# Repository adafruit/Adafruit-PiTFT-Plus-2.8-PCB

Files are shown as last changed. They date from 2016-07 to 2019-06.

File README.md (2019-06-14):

## Adafruit PiTFT 2.8 Plus PCB

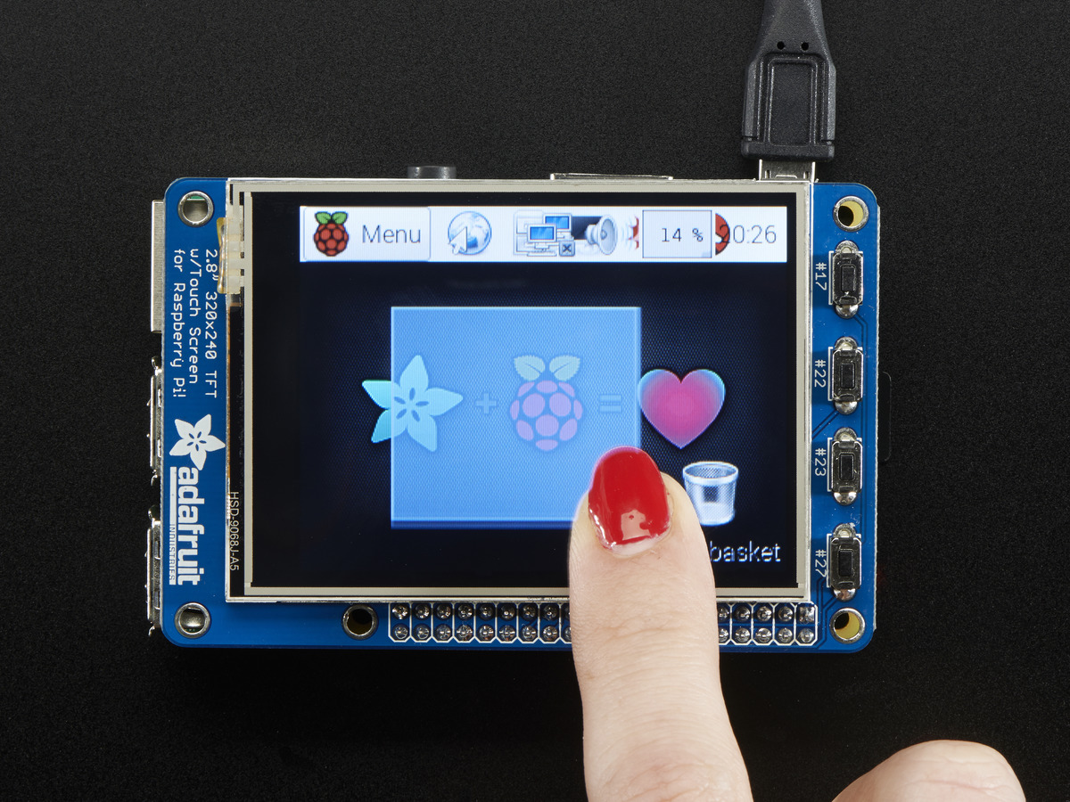
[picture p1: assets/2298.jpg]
&nbsp; 
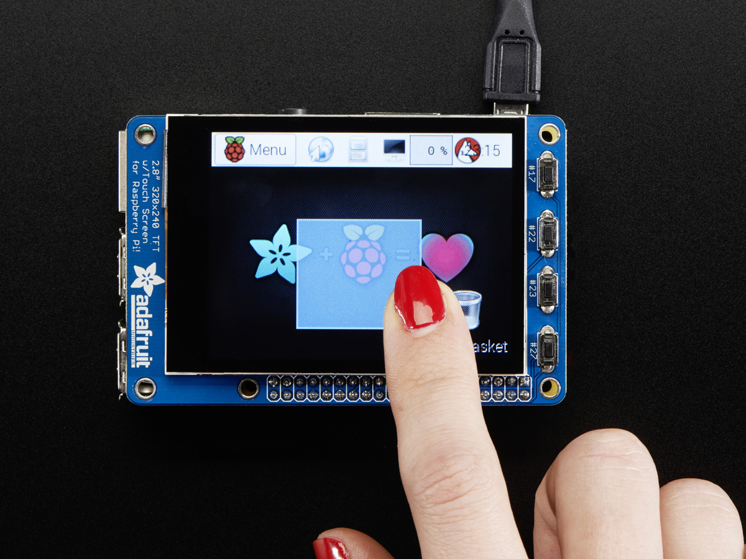
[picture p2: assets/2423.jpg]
<br/>
Click the image or links below to go to a specific product in the Adafruit shop.

PCB files for the Adafruit PiTFT Plus 2.8" Display. Format is EagleCAD schematic and board layout
* Resistive Screen https://www.adafruit.com/product/2298
* Capacitive Touch Screen https://www.adafruit.com/product/2423

### DESCRIPTION
Are these not the cutest little displays for the Raspberry Pi? They feature a 2.8" display with 320x240 16-bit color pixels and a  resistive touchscreen or capacitive touch overlay..

This updated design fits perfectly onto the Pi Zero, Pi 3, Pi 2 or Model A+, B+! (Any Pi with a 2x20 connector) Not for use with an old Pi 1 with 2x13 connector If you'd like to use a 2.8" display with the original Pi A or Pi B, check out the Model B version. This version also has all 40 pins GPIO pins brought out so you can connect a 40-pin GPIO cable underneath. Now that it's the same outline as a Pi 3/2/B+ it fits well on top of a Pi in our Raspberry Pi Enclosure base and can use our faceplate for a compact touchscreen Pi

The display and touchscreen uses the hardware I2C Pins (SDA & SCL), SPI pins (SCK, MOSI, MISO, CE0) as well as GPIO #25 and #24. All other GPIO are unused and you can still share the I2C pins with sensors, LED drivers, etc. Since we had a tiny bit of space, there's 4 slim tactile switches wired to four GPIOs, that you can use if you want to make a basic user interface. For example, you can use one as a power on/off button.

### License

Adafruit invests time and resources providing this open source design, please support Adafruit and open-source hardware by purchasing products from [Adafruit.com](https://www.adafruit.com)!

Creative Commons Attribution, Share-Alike license, check license.txt for more information All text above must be included in any redistribution - 
See license.txt for more information.

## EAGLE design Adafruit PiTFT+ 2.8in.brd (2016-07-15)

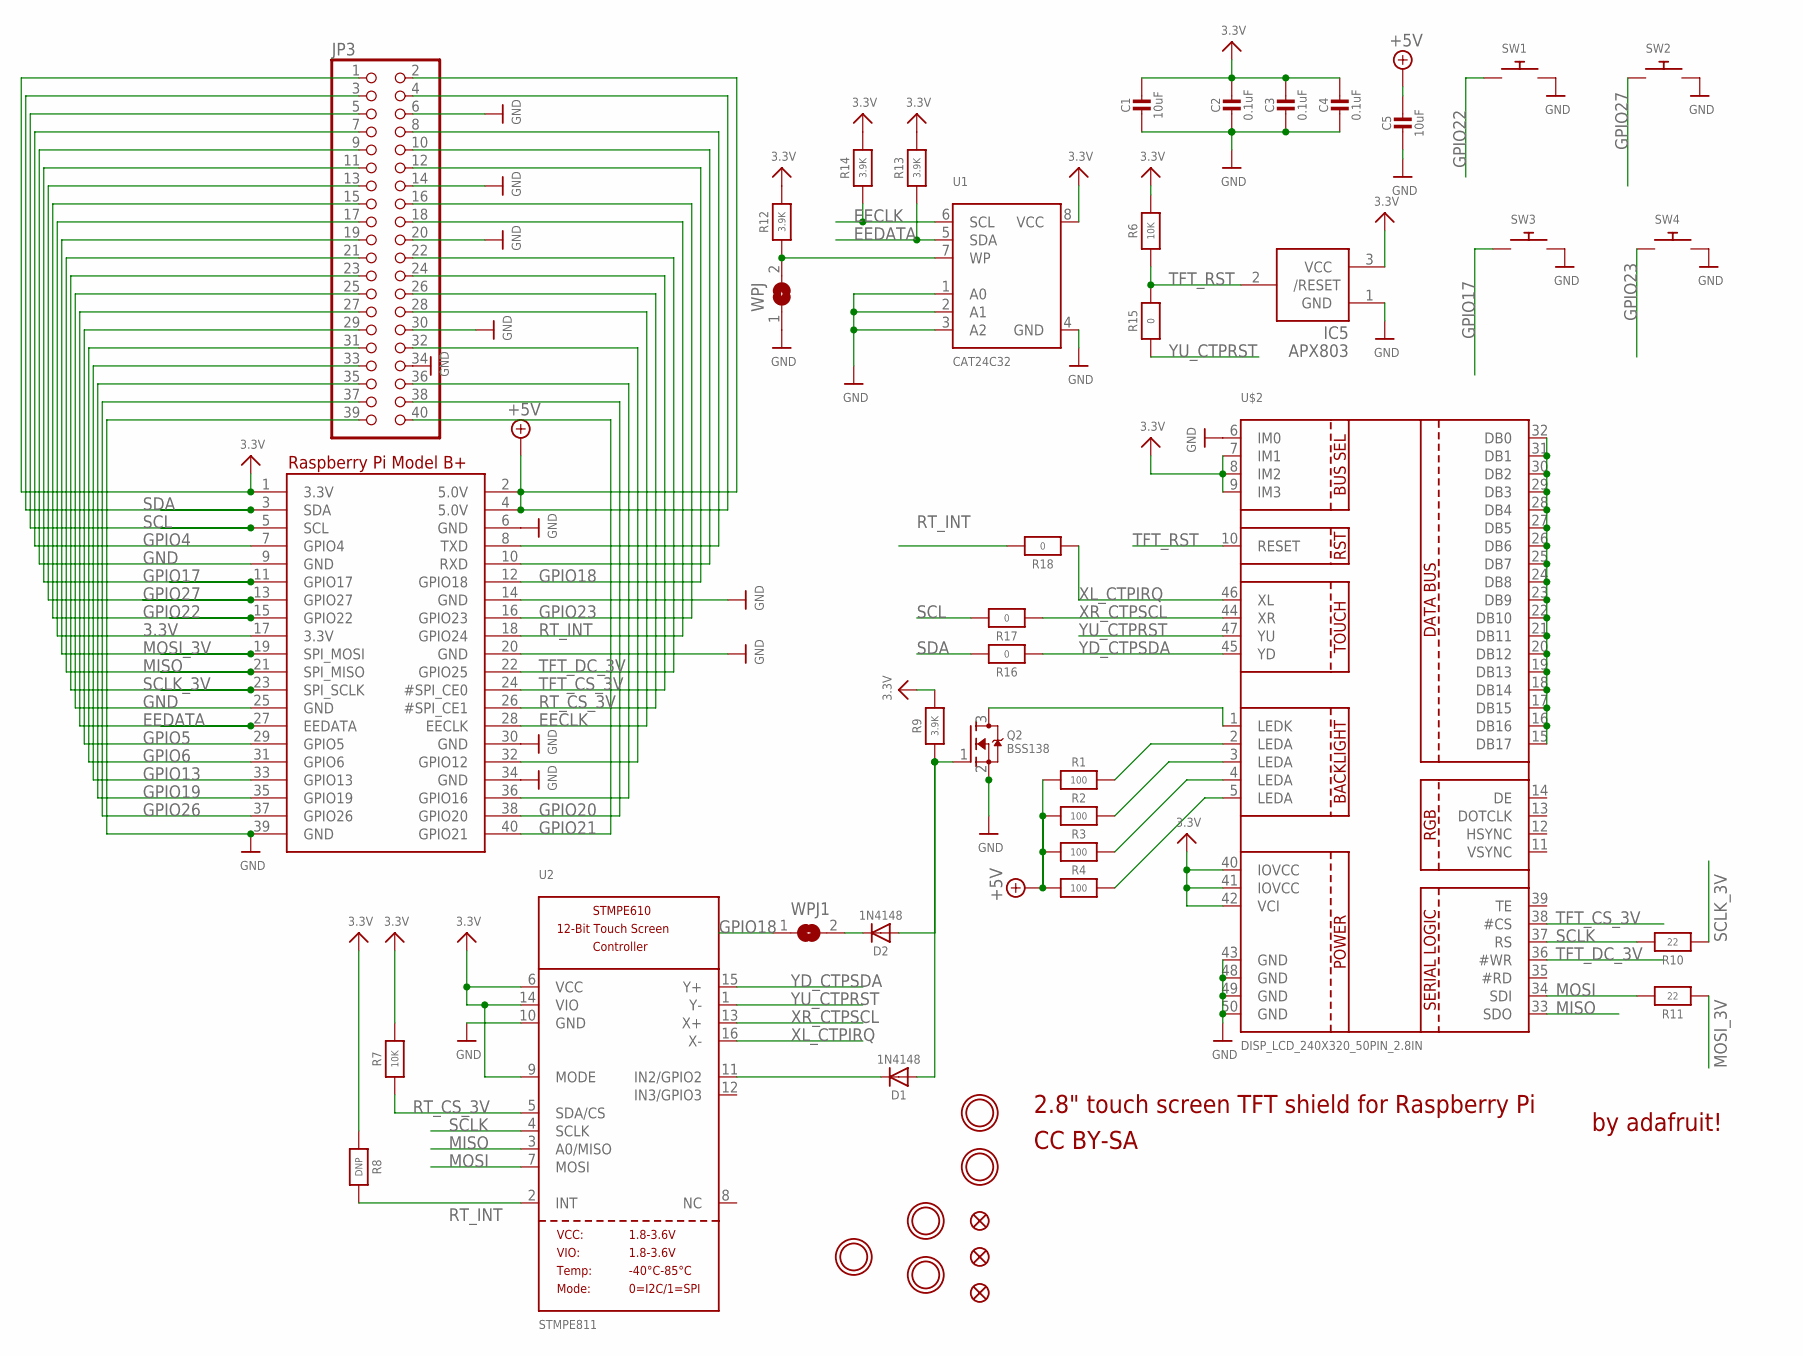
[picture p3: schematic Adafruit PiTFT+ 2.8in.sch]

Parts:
C1, C5: 10uF; 0805-NO
C2, C3, C4: 0.1uF; 0805-NO
D1, D2: 1N4148; SOD-323
IC5: APX803; SOT23
JP3: PINHD-2X20_SMT; 2X20_SMT_MALE
Q2: BSS138; SOT23-WIDE
R1, R2, R3, R4: 100; 0805-NO
R6, R7: 10K; 0805-NO
R8: DNP; 0805-NO
R9, R12, R13, R14: 3.9K; 0805-NO
R10, R11: 22; 0805-NO
R15, R16, R17, R18: 0; 0805-NO
RPI1: RASPBERRYPI_BPLUS_SHIELD_NODIM
SW1, SW2, SW3, SW4: SWITCH_PUSHBUTTONEVQ-PE; TACT_PANA-EVQ
U1: CAT24C32; SOIC8_150MIL
U2: STMPE811; QFN16_3MM
U$2: DISP_LCD_240X320_50PIN_2.8IN; TFT_2.83IN_240X320_50PIN
U$3, U$15, U$16, U$17, U$40: MOUNTINGHOLE3.0THIN; MOUNTINGHOLE_3.0_PLATEDTHIN
U$10, U$11, U$18: FIDUCIAL""; FIDUCIAL_1MM
WPJ, WPJ1: SOLDERJUMPERCLOSED; SOLDERJUMPER_CLOSEDWIRE

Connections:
3.3V: C1.1, C2.1, C3.1, C4.1, IC5.3 (VCC), JP3.1, JP3.17, R6.2, R7.2, R8.1, R9.2, R12.2, R13.2, R14.2, RPI1.1 (3.3V), RPI1.17 (3.3V), U1.8 (VCC), U2.6 (VCC), U2.9 (MODE), U2.14 (VIO), U$2.7 (IM1), U$2.8 (IM2), U$2.9 (IM3), U$2.40 (IOVCC), U$2.41 (IOVCC), U$2.42 (VCI)
+5V: C5.1, JP3.2, JP3.4, R1.1, R2.1, R3.1, R4.1, RPI1.2 (5.0V), RPI1.4 (5.0V)
EECLK: JP3.28, R14.1, RPI1.28 (EECLK), U1.6 (SCL)
EEDATA: JP3.27, R13.1, RPI1.27 (EEDATA), U1.5 (SDA)
GND: C1.2, C2.2, C3.2, C4.2, C5.2, IC5.1 (GND), JP3.6, JP3.9, JP3.14, JP3.20, JP3.25, JP3.30, JP3.34, JP3.39, Q2.2 (S), RPI1.6 (GND), RPI1.9 (GND), RPI1.14 (GND), RPI1.20 (GND), RPI1.25 (GND), RPI1.30 (GND), RPI1.34 (GND), RPI1.39 (GND), SW1.P$2, SW2.P$2, SW3.P$2, SW4.P$2, U1.1 (A0), U1.2 (A1), U1.3 (A2), U1.4 (GND), U2.10 (GND), U$2.6 (IM0), U$2.43 (GND), U$2.48 (GND), U$2.49 (GND), U$2.50 (GND), WPJ.1
GPIO4: JP3.7, RPI1.7 (GPIO4)
GPIO5: JP3.29, RPI1.29 (GPIO5)
GPIO6: JP3.31, RPI1.31 (GPIO6)
GPIO12: JP3.32, RPI1.32 (GPIO12)
GPIO13: JP3.33, RPI1.33 (GPIO13)
GPIO16: JP3.36, RPI1.36 (GPIO16)
GPIO17: JP3.11, RPI1.11 (GPIO17), SW3.P$1
GPIO18: JP3.12, RPI1.12 (GPIO18), WPJ1.1
GPIO19: JP3.35, RPI1.35 (GPIO19)
GPIO20: JP3.38, RPI1.38 (GPIO20)
GPIO21: JP3.40, RPI1.40 (GPIO21)
GPIO22: JP3.15, RPI1.15 (GPIO22), SW1.P$1
GPIO23: JP3.16, RPI1.16 (GPIO23), SW4.P$1
GPIO26: JP3.37, RPI1.37 (GPIO26)
GPIO27: JP3.13, RPI1.13 (GPIO27), SW2.P$1
MISO: JP3.21, RPI1.21 (SPI_MISO), U2.3 (A0/MISO), U$2.33 (SDO)
MOSI: R11.2, U2.7 (MOSI), U$2.34 (SDI)
MOSI_3V: JP3.19, R11.1, RPI1.19 (SPI_MOSI)
unnamed: Q2.3 (D), U$2.1 (LEDK)
unnamed: R1.2, U$2.2 (LEDA)
unnamed: R2.2, U$2.3 (LEDA)
unnamed: R3.2, U$2.4 (LEDA)
unnamed: D1.C, U2.11 (IN2/GPIO2)
unnamed: D2.C, WPJ1.2
unnamed: U$2.15 (DB17), U$2.16 (DB16), U$2.17 (DB15), U$2.18 (DB14), U$2.19 (DB13), U$2.20 (DB12), U$2.21 (DB11), U$2.22 (DB10), U$2.23 (DB9), U$2.24 (DB8), U$2.25 (DB7), U$2.26 (DB6), U$2.27 (DB5), U$2.28 (DB4), U$2.29 (DB3), U$2.30 (DB2), U$2.31 (DB1), U$2.32 (DB0)
unnamed: R4.2, U$2.5 (LEDA)
unnamed: R12.1, U1.7 (WP), WPJ.2
unnamed: D1.A, D2.A, Q2.1 (G), R9.1
RT_CS_3V: JP3.26, R7.1, RPI1.26 (#SPI_CE1), U2.5 (SDA/CS)
RT_INT: JP3.18, R8.2, R18.2, RPI1.18 (GPIO24), U2.2 (INT)
RXD: JP3.10, RPI1.10 (RXD)
SCL: JP3.5, R17.2, RPI1.5 (SCL)
SCLK: R10.2, U2.4 (SCLK), U$2.37 (RS)
SCLK_3V: JP3.23, R10.1, RPI1.23 (SPI_SCLK)
SDA: JP3.3, R16.2, RPI1.3 (SDA)
TFT_CS_3V: JP3.24, RPI1.24 (#SPI_CE0), U$2.38 (#CS)
TFT_DC_3V: JP3.22, RPI1.22 (GPIO25), U$2.36 (#WR)
TFT_RST: IC5.2 (/RESET), R6.1, R15.2, U$2.10 (RESET)
TXD: JP3.8, RPI1.8 (TXD)
XL_CTPIRQ: R18.1, U2.16 (X-), U$2.46 (XL)
XR_CTPSCL: R17.1, U2.13 (X+), U$2.44 (XR)
YD_CTPSDA: R16.1, U2.15 (Y+), U$2.45 (YD)
YU_CTPRST: R15.1, U2.1 (Y-), U$2.47 (YU)

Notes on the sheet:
2.8" touch screen TFT shield for Raspberry Pi
by adafruit!
CC BY-SA

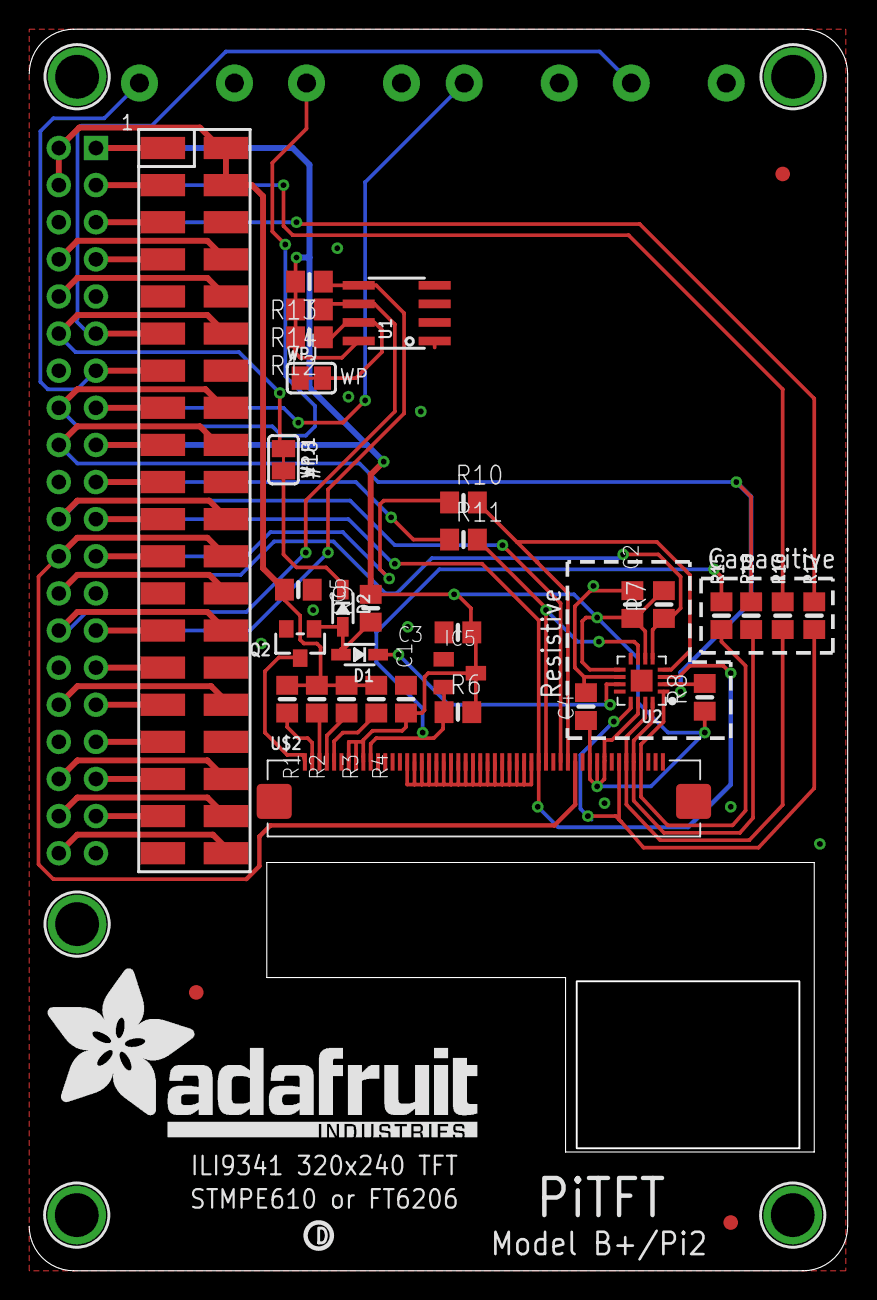
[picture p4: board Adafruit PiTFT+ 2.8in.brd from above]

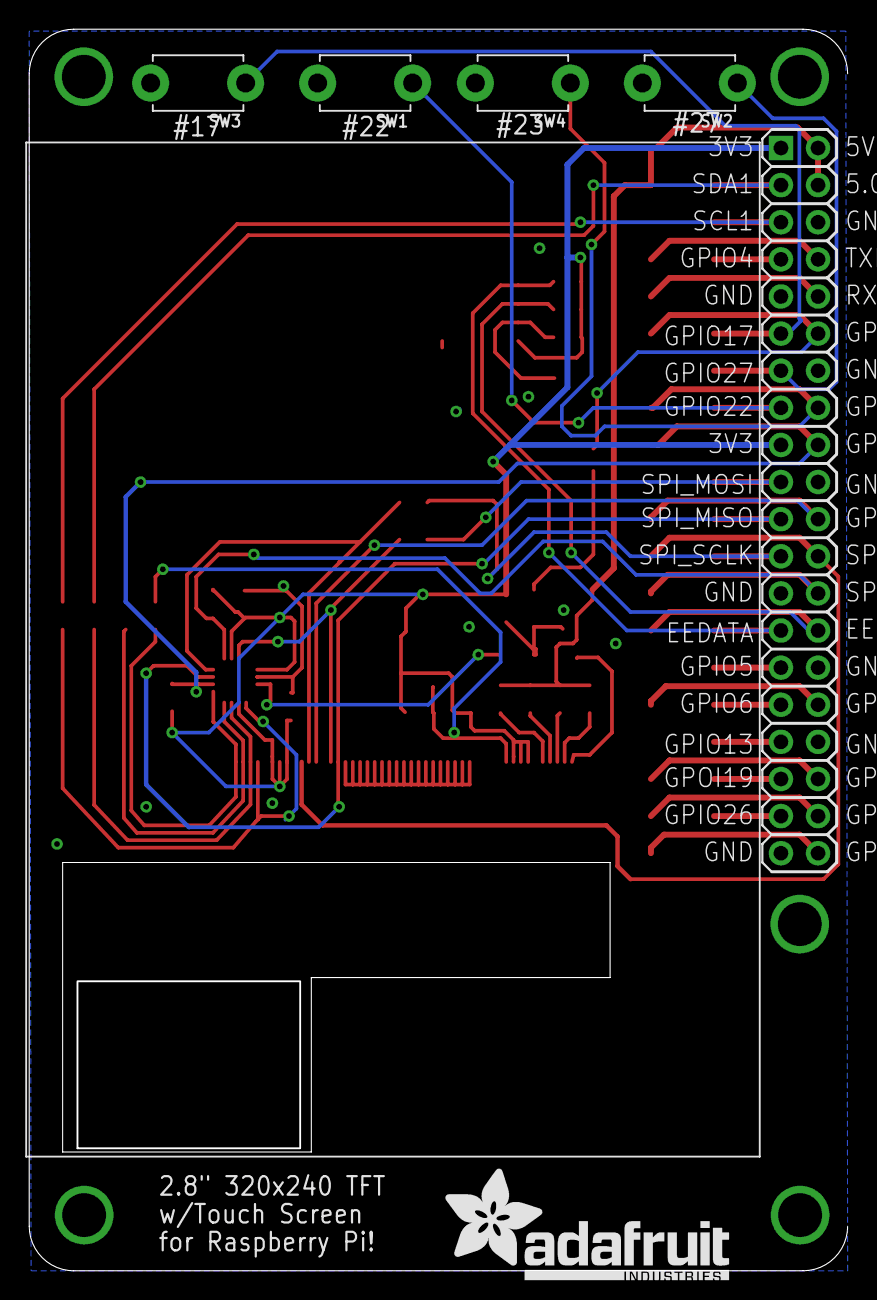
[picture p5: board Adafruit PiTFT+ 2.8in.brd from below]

Board: 2 copper layers, 56.0 x 85.0 mm, 48 parts (7 on the bottom side), 48 nets.

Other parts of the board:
U$12: PCBFEAT-REV-040
U$23: ADAFRUIT_TEXT_20MM
U$42: ADAFRUIT_TEXT_30MM
